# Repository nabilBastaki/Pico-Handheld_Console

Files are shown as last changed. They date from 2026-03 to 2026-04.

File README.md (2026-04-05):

# 🎮 Raspberry Pi Pico 2W Handheld Console (Version 2.0) - No battery - Piezo Buzzer circuit fixed.

Welcome to the Pico 2W Handheld Console project! This repository contains all the hardware files, software firmware, and step-by-step instructions needed to build your own portable gaming device.

---

## 📂 Project Structure

* **/Hardware**: Contains KiCad PCB design files, schematics, and the Bill of Materials (BOM).
* **/Software**: Contains the MicroPython firmware (`main.py`, `diagnostics.py`, `ili9341.py`, `boot.py`).
* **/Guidelines**: **Start here!** These are your step-by-step assembly and user manuals in PDF format.

---

## 🚀 Getting Started (The Build Process)

Please follow the documentation in the **/Guidelines** folder in this specific order:

1.  **01: Soldering & Assembly (PDF)**: Learn the "Golden Rule" of assembly and how to handle the ESOP-8 charger and SOT-23-6 MOSFET.
2.  **02: Initial Power-On Check (PDF)**: Perform critical "Cold Checks" with a multi-meter to ensure your board is safe.
3.  **03: Software Installation (PDF)**: Upload the firmware files to your Pico 2W using Thonny—no coding required!
4.  **04: Console User Manual (PDF)**: Learn how to charge your device, use the "Hold-to-Setup" menu, and handle the LiPo battery safely.
5.  **05: Hardware Troubleshooting (PDF)**: If your screen is white or the buzzer won't stop, use this table to find the fix.
6.  **06: Sign_Off_Sheet (PDF)**: Checklist that includes milestones for each team to keep track of progress and ensure correct procedures.

---

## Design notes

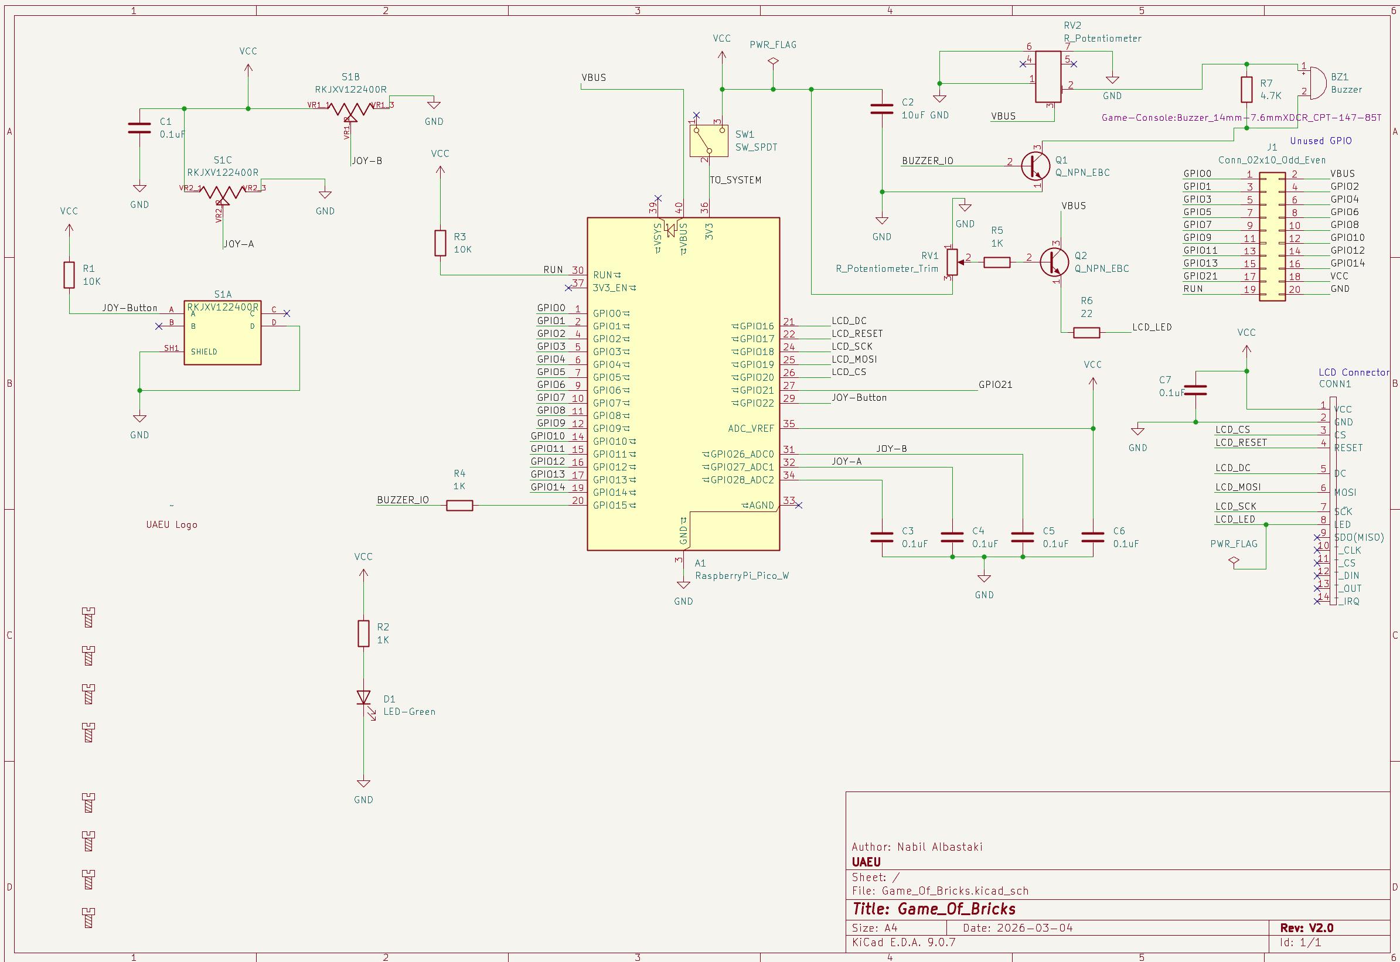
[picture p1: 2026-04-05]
Hardware/Game_Of_Bricks-V2.jpeg

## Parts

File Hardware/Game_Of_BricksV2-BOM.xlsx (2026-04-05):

Reference | Qty | Value | DNP | Exclude from BOM | Exclude from Board | Footprint | Datasheet
A1 | 1 | RaspberryPi_Pico_W |  |  |  | Game-Console:RaspberryPi_Pico_Common_THT | https://datasheets.raspberrypi.com/picow/pico-w-datasheet.pdf
BZ1 | 1 | Buzzer |  |  |  | Game-Console:Buzzer_14mm-7.6mmXDCR_CPT-147-85T | ~
C1*C3*C4*C5*C6*C7 | 6 | 0.1uF |  |  |  | Game-Console:C_1206_3216Metric_Pad1.33x1.80mm_HandSolder | ~
C2 | 1 | 10uF |  |  |  | Game-Console:C_1206_3216Metric_Pad1.33x1.80mm_HandSolder | ~
CONN1 | 1 | ~ |  |  |  | Game-Console:PinSocket_1x14_P2.54mm_Vertical
D1 | 1 | LED-Green |  |  |  | Game-Console:LED_1206_3216Metric_Pad1.42x1.75mm_HandSolder | ~
H1*H2*H3*H4*H5*H6*H7*H8 | 8 | MountingScrew |  | Excluded from BOM |  | Game-Console:MountingHole_3mm | ~
J1 | 1 | Conn_02x10_Odd_Even |  |  |  | Game-Console:PinHeader_2x10_P2.54mm_Horizontal | ~
Q1*Q2 | 2 | Q_NPN_EBC |  |  |  | Game-Console:TO-92L_HandSolder | ~
R1*R3 | 2 | 10K |  |  |  | Game-Console:R_1206_3216Metric_Pad1.30x1.75mm_HandSolder | ~
R2*R4*R5 | 3 | 1K |  |  |  | Game-Console:R_1206_3216Metric_Pad1.30x1.75mm_HandSolder | ~
R6 | 1 | 22 |  |  |  | Game-Console:R_1206_3216Metric_Pad1.30x1.75mm_HandSolder | ~
R7 | 1 | 4.7K |  |  |  | Game-Console:R_1206_3216Metric_Pad1.30x1.75mm_HandSolder | ~
RV1 | 1 | R_Potentiometer_Trim |  |  |  | Game-Console:TRIM_3352T-1-502LF | ~
RV2 | 1 | R_Potentiometer |  |  |  | Game-Console:Potentiometer_RK10J11E_Volume | ~
S1 | 1 | RKJXV122400R |  |  |  | Game-Console:SW_RKJXV122400R
SW1 | 1 | SW_SPDT |  |  |  | Game-Console:SW_Slide_SPDT_Angled_CK_OS102011MA1Q | ~

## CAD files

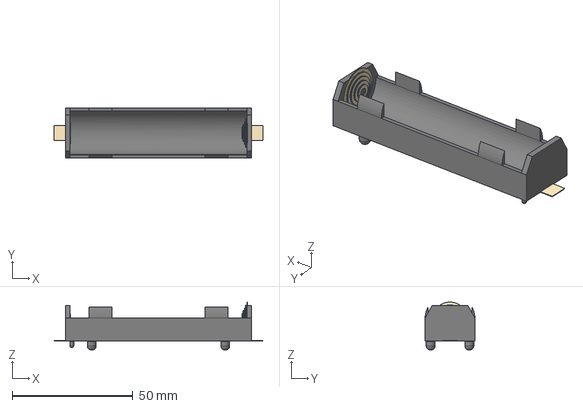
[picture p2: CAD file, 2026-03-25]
Hardware/KiCad_Lib/3dshapes/BatteryHolder_Keystone_1042_1x18650.step
86.4 x 20.6 x 19.8 mm

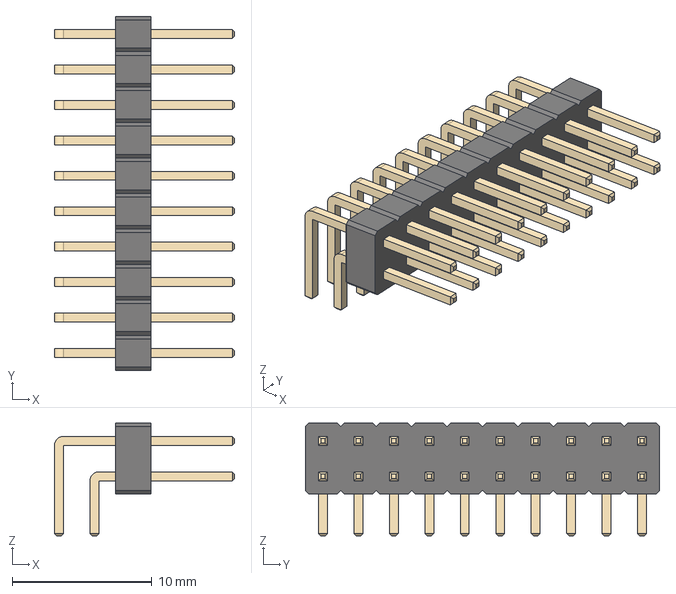
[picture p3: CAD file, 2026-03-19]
Hardware/KiCad_Lib/3dshapes/PinHeader_2x10_P2.54mm_Horizontal.step
12.9 x 25.4 x 8.08 mm

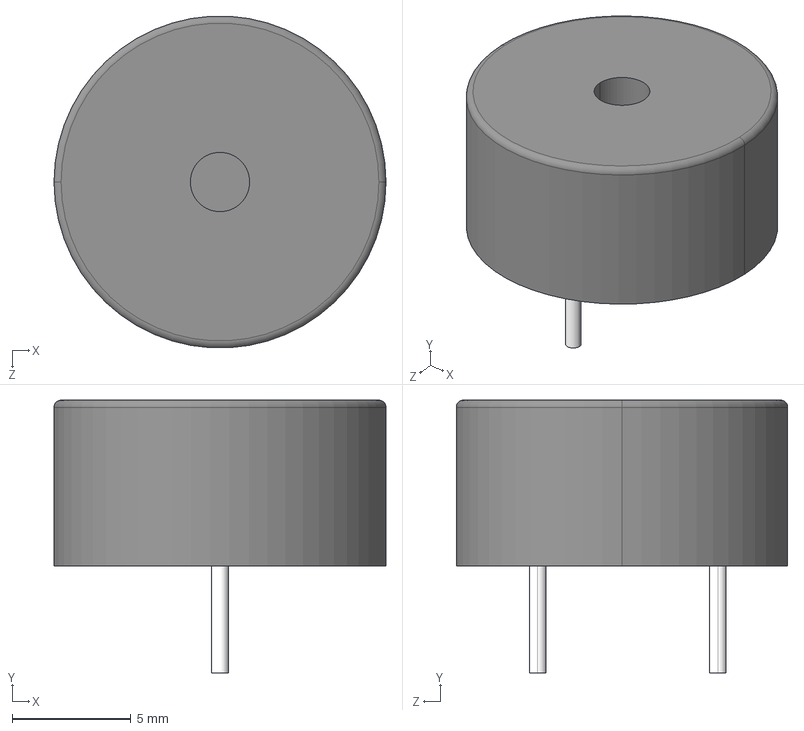
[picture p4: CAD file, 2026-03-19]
Hardware/KiCad_Lib/3dshapes/CPT-147-85T.step
14.0 x 11.5 x 14.0 mm

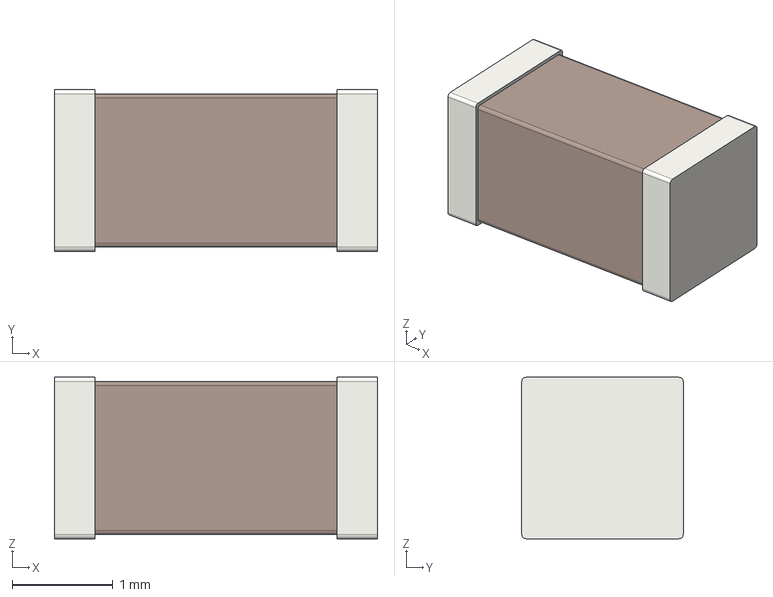
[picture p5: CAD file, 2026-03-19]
Hardware/KiCad_Lib/3dshapes/C_1206_3216Metric.step
3.20 x 1.60 x 1.60 mm

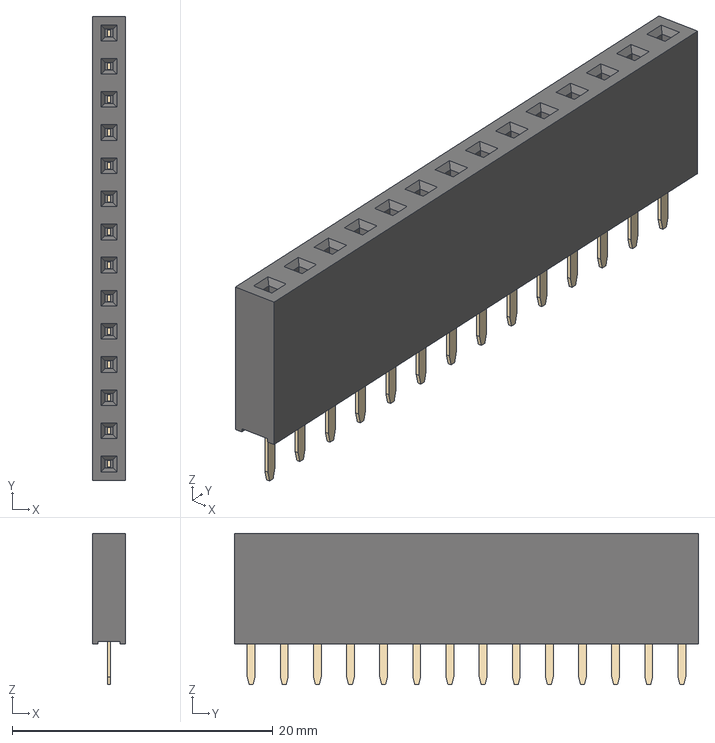
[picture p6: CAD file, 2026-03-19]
Hardware/KiCad_Lib/3dshapes/PinSocket_1x14_P2.54mm_Vertical.step
2.54 x 35.6 x 11.6 mm

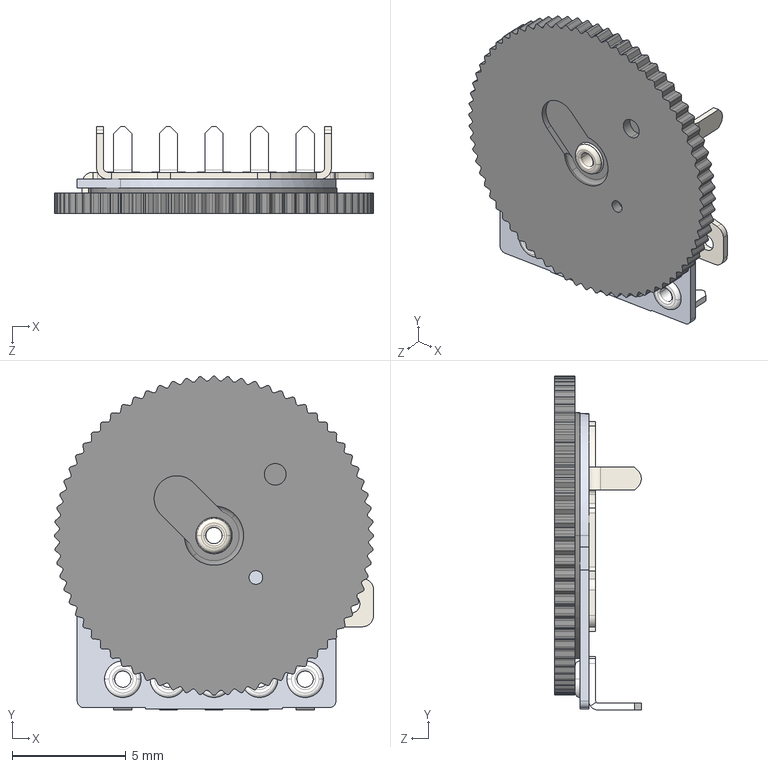
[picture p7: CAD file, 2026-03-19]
Hardware/KiCad_Lib/3dshapes/RK10J11E0034_Volume_VR1.step
14.0 x 14.6 x 3.80 mm

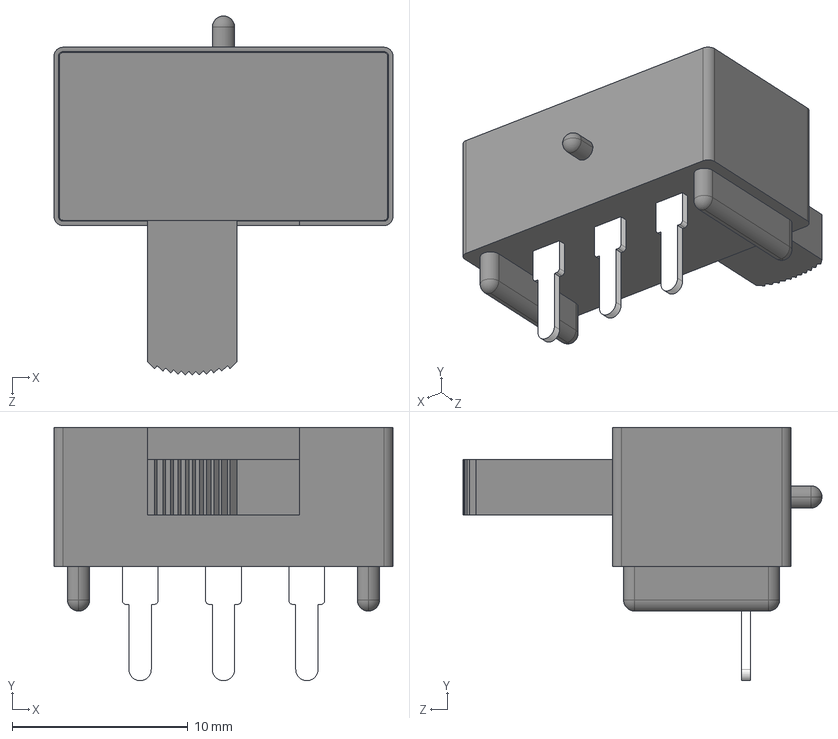
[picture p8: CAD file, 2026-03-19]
Hardware/KiCad_Lib/3dshapes/SPDT_Slide_L102021ML04Q.step
19.3 x 14.4 x 20.4 mm

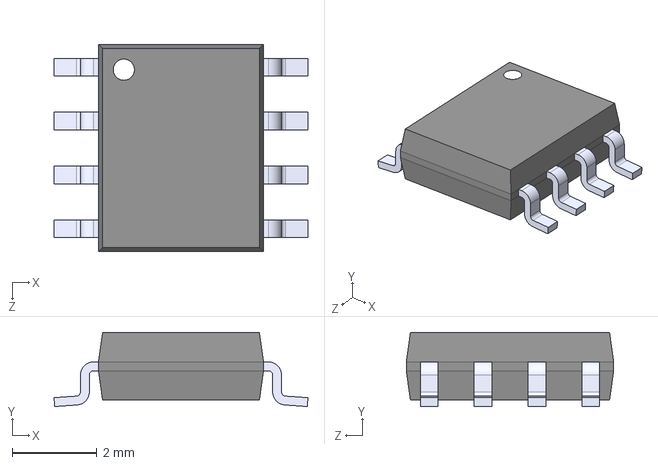
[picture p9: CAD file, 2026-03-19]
Hardware/KiCad_Lib/3dshapes/TP4056.step
6.00 x 1.75 x 4.90 mm

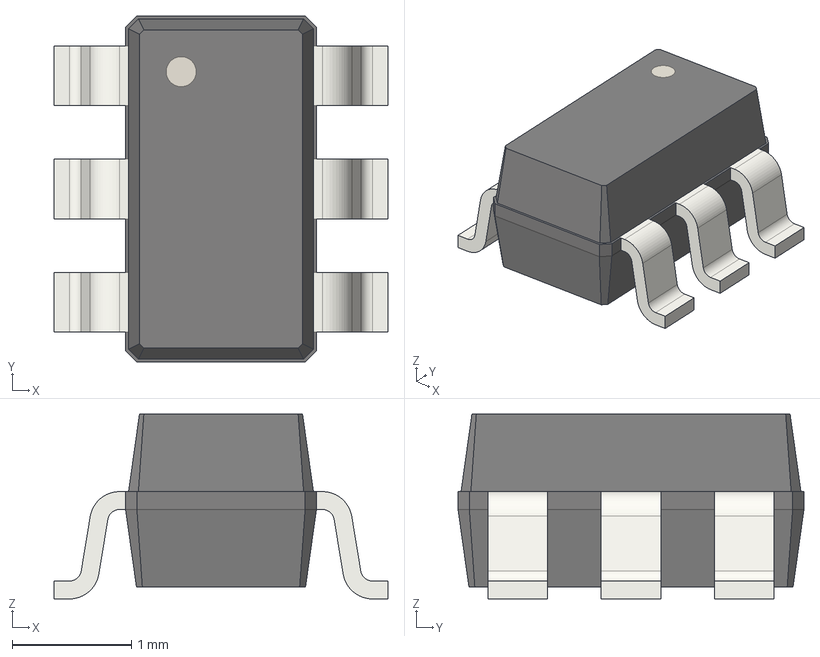
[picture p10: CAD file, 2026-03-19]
Hardware/KiCad_Lib/3dshapes/SOT-23-6.step
2.80 x 2.90 x 1.55 mm

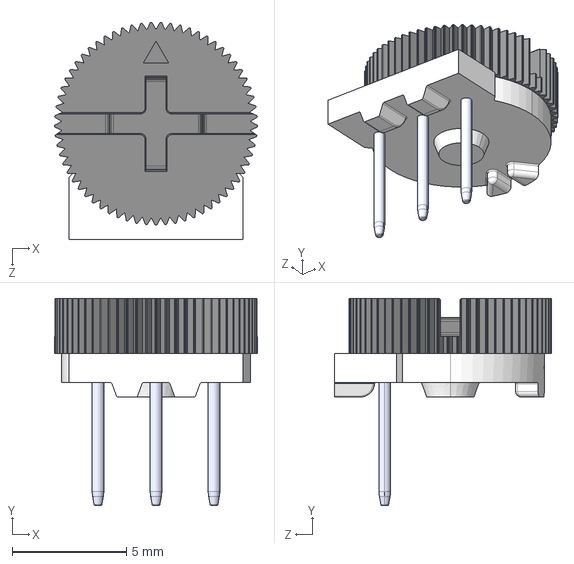
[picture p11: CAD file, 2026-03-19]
Hardware/KiCad_Lib/3dshapes/3352T-1-502LF.step
8.89 x 9.07 x 9.52 mm

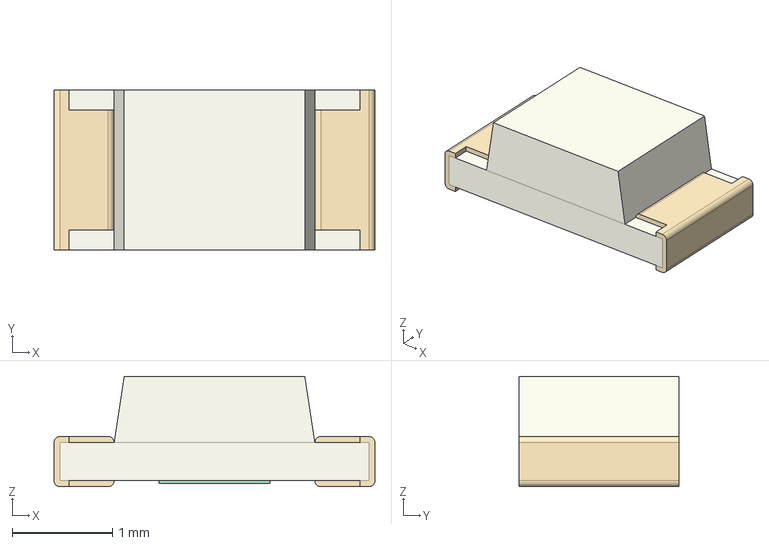
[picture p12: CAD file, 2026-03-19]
Hardware/KiCad_Lib/3dshapes/LED_1206_3216Metric.step
3.20 x 1.60 x 1.10 mm

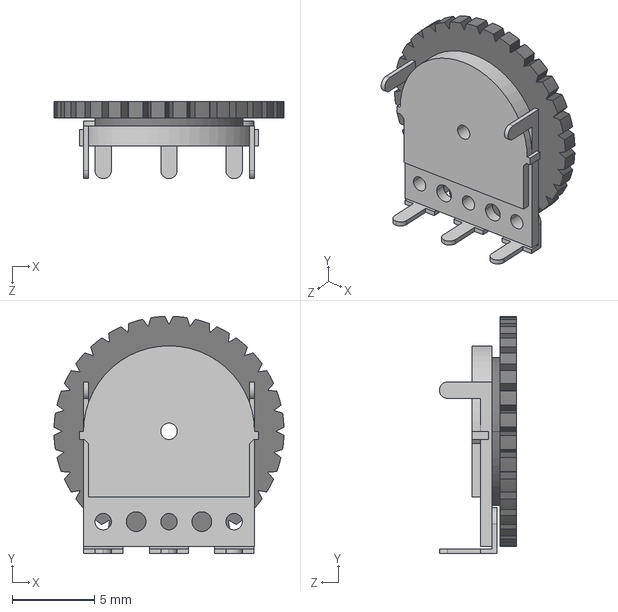
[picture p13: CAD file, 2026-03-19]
Hardware/KiCad_Lib/3dshapes/User Library-RV100F-30-4K1-B15 Potentiometer.STEP
14.0 x 14.4 x 4.70 mm

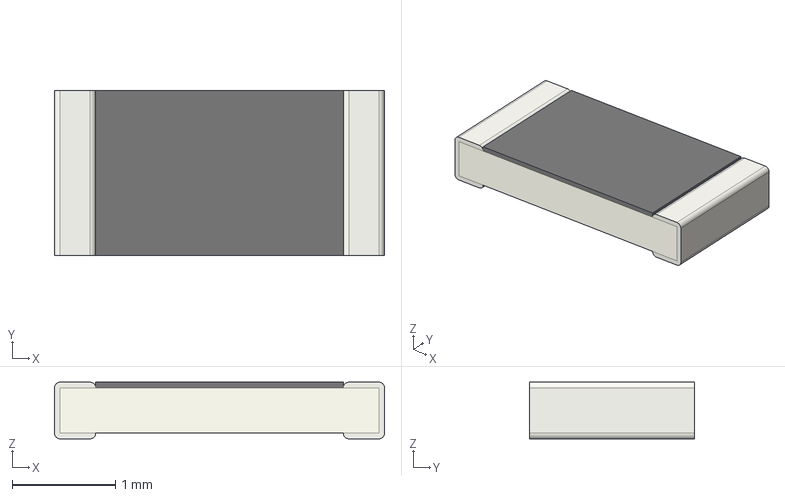
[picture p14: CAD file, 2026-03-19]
Hardware/KiCad_Lib/3dshapes/R_1206_3216Metric.step
3.20 x 1.60 x 0.55 mm

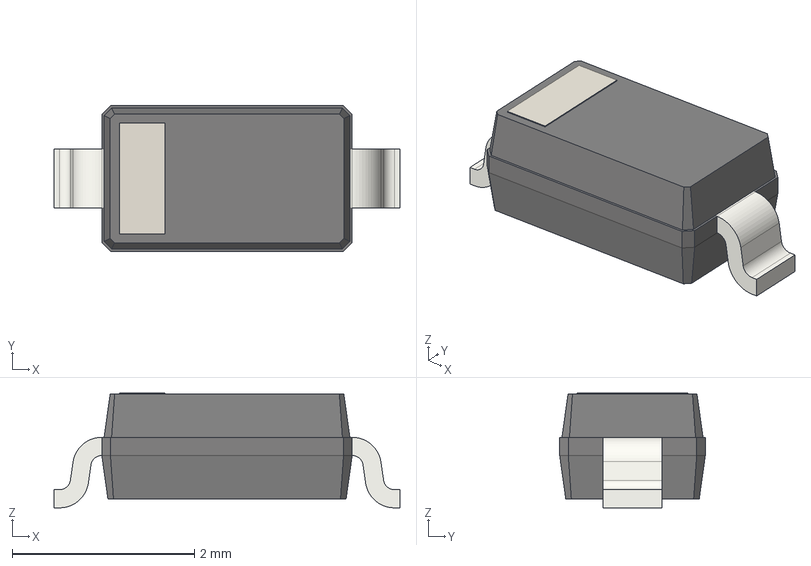
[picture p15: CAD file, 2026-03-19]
Hardware/KiCad_Lib/3dshapes/D_SOD-123.step
3.80 x 1.60 x 1.26 mm

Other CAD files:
Hardware/KiCad_Lib/3dshapes/MountingHoleScrew3mm.step

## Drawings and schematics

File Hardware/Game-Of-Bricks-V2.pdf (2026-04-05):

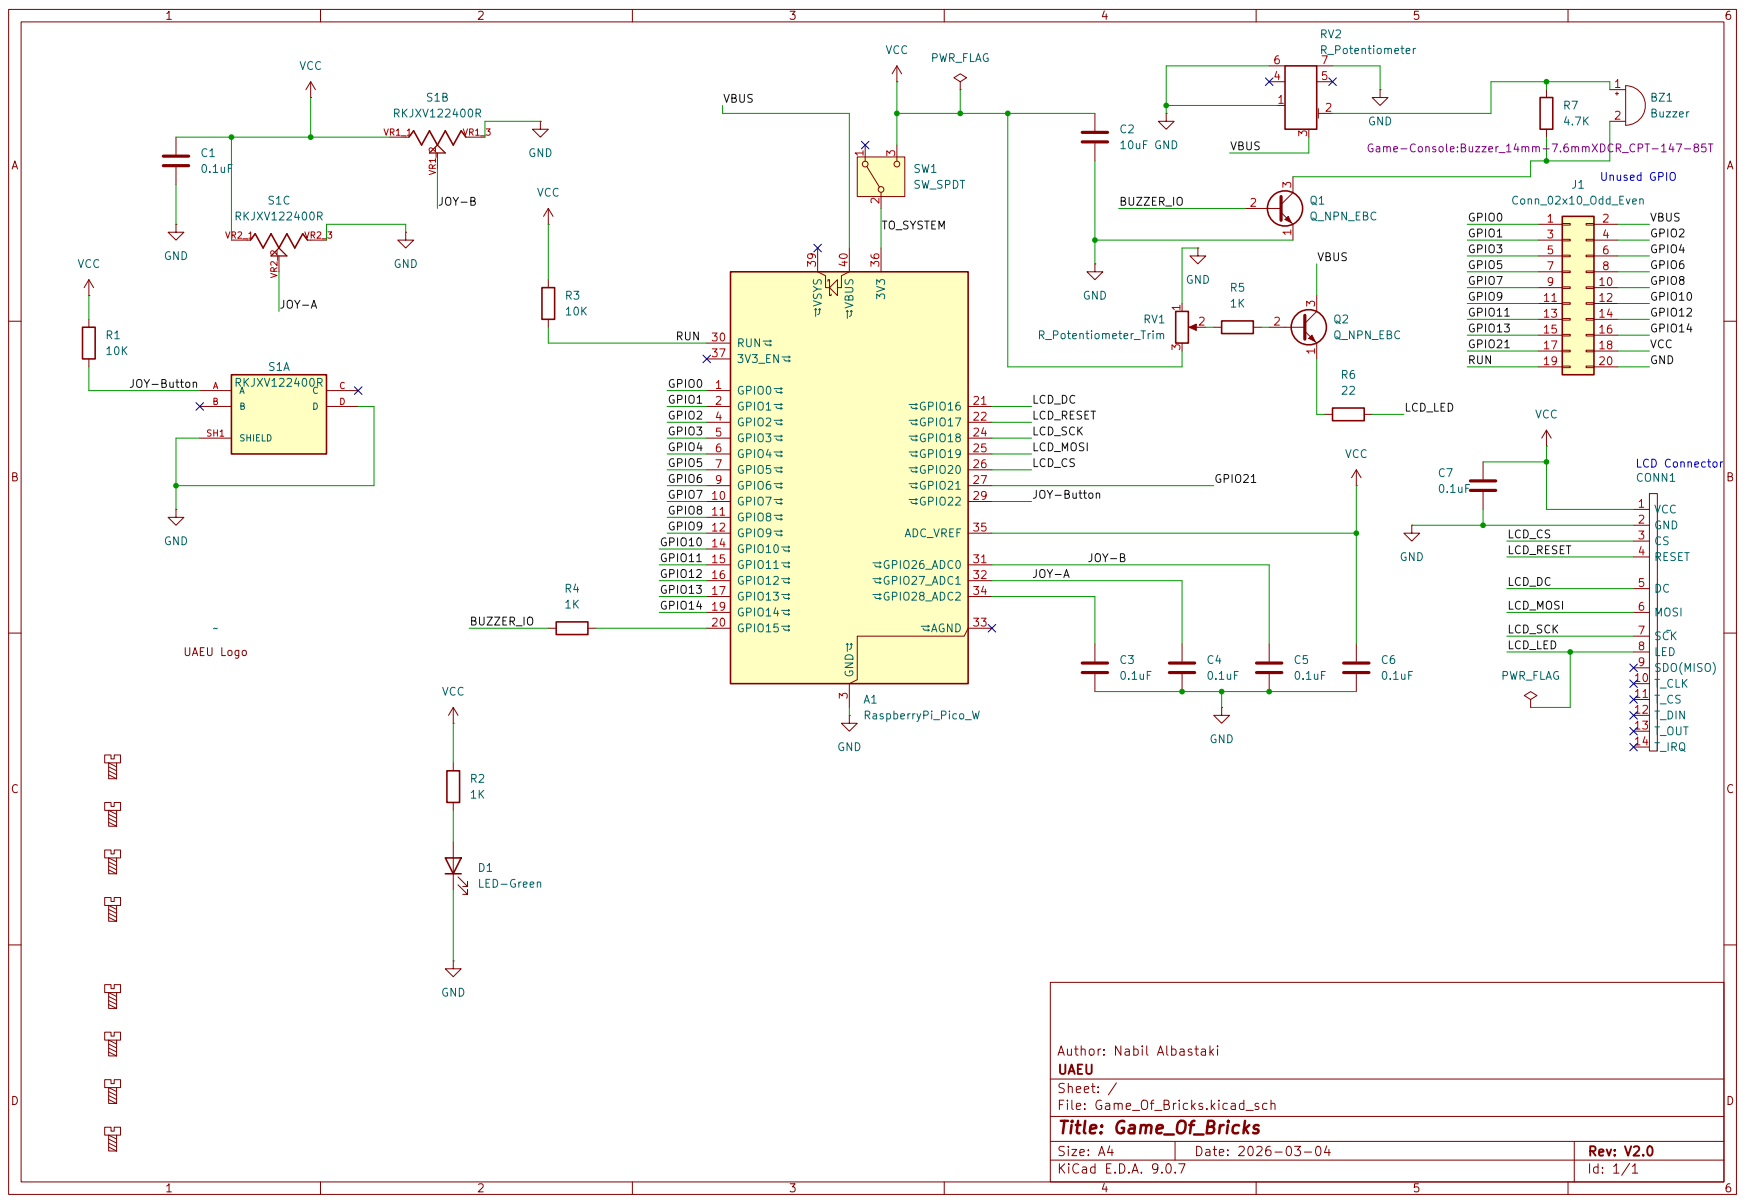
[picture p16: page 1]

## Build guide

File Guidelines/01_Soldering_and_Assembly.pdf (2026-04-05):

Guide 01: Soldering & Assembly
The "Golden Rule" remains to work from the center outward and from shortest to tallest components.
- Step 1: Resistors & Capacitors: Solder the 10kΩ pull-up resistors (R1, R3) and the 0.1µF decoupling capacitors (C1, C3-C7).
- Step 2: Transistors: Solder the NPN transistors (Q1, Q2).
- Step 3: Buzzer & Joystick: Install these taller through-hole parts. Ensure the joystick sits flush against the PCB.
- Step 4: Headers: Solder the two 20-pin female headers for the Raspberry Pi Pico 2W and the 8-pin connector for the LCD.
- Note: Instructions regarding the TP4056 ESOP-8 charger and the FS8205A MOSFET are now obsolete as these components have been removed.

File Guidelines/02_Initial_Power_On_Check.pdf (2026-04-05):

Guide 02: Initial Power-On Check
Since the battery circuit is removed, safety checks focus entirely on the USB 5V (VBUS) rail.
- The Visual Inspection: Check for solder bridges on the female headers and the pins of the NPN transistors (Q1, Q2).
- Multi-Meter "Short Circuit" Test: With the meter in Continuity Mode, place one probe on a GND pin and the other on the VBUS pin. If it stays silent, the power rail is safe.
- Stage 1 Power Up: Plug the Pico 2W into your computer via USB. The tiny green LED on the Pico should blink, indicating the 5V rail is active.
- Note: You no longer need to check battery terminals or the heat of the (removed) charger and MOSFET chips

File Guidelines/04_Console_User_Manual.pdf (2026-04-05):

Guide 04: Console User Manual
The console is now a USB-powered device.
- Power: The device turns on when a Micro-USB cable is connected to the Raspberry Pi Pico.
- Buzzer: The buzzer is now driven by an NPN transistor (Q1) via GPIO15 (BUZZER_IO) for improved sound quality.
- Setup Menu: To enter settings, hold the Joystick Button down while connecting the USB power or flipping the system switch.
- Note: All sections regarding LiPo battery safety, charging LEDs (Red/Green), and low battery warnings are no longer applicable.

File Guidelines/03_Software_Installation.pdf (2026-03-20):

This guide will walk your company through installing the development environment, connecting to the hardware, and transferring the firmware to the Raspberry Pi Pico 2WYou can watch similar steps on YouTube: (https://youtu.be/V5yQ2-BPWLw?si=BpnSXxz7sOUPejI9)

### 1. Download & Install Thonny IDE

Before connecting your hardware, you must install Thonny on your computer.
- For Windows: * Go to thonny.org and download the Windows Installer (64-bit).
- Run the .exe file. If a "Windows protected your PC" message appears, click More info → Run anyway.
- For macOS: * Go to thonny.org and download the .pkg file.
- If blocked by security settings, go to System Settings > Privacy & Security and click Open Anyway.

### 2. Initializing Thonny (First-Time Setup)

Configure Thonny to communicate with the MicroPython language on your console.
1. Connect the Console: Plug your Raspberry Pi Pico 2W into the computer using a micro-USB data cable.
2. Enable the Files Sidebar: In the top menu, go to View Files → .
3. Select the Interpreter: Click the text in the bottom-right corner (likely "Python 3.x") and select MicroPython (Raspberry Pi Pico) from the list.
4. The "Handshake" (Reset): Click the Red Stop Button in the top toolbar.
- The Shell at the bottom should display: MicroPython v1.2x.x... on Raspberry Pi Pico.
- The Files pane will now split into "This computer" (top) and "Raspberry Pi Pico" (bottom).

### 3. Uploading the Firmware

Move the project files from your company's computer to the console's memory.
1. Locate the Files: In the top section (This computer), navigate to your /Software folder.
2. Select the Firmware: Highlight main.py, diagnostics.py, ili9341.py, and boot.py.
3. Transfer: Right-click the highlighted files and select "Upload to /". They will appear in the bottom section (Raspberry Pi Pico).

### 4. Functional Testing & Switching Scripts

The Pico can only run one program at a time. Follow this workflow to test your build.
1. Run Diagnostics: Double-click diagnostics.py in the bottom section and click the Green Play Button.
2. Test Hardware: Verify the screen, joystick, and buzzer are responsive.
3. Switch to Main Game:
- STOP: You must click the Red Stop Button first to end the diagnostic script.
- OPEN: Click the tab for main.py at the top of the editor.
- PLAY: Click the Green Play Button to launch the main console interface.

### 5. Troubleshooting for Companies

- "Device is Busy": A script is currently running. Click the Red Stop Button before trying to upload or run new files.
- Pico Not Found: Ensure you are using a Data Cable. Some cables are "poweronly" and cannot transfer code.
- Missing "Upload to /": Ensure you have right-clicked the files in the top (Computer) section of the pane.

Next Step: Proceed to Guide 04: Console_User_Manual to connect the battery and complete the build!

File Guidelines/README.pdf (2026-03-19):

# 🎮 Raspberry Pi Pico 2W Handheld Console

Welcome to the Pico 2W Handheld Console project! This repository contains all the hardware files, software firmware, and step-by-step instructions needed to build your own portable gaming device.

## 📂 Project Structure

- /Hardware: Contains KiCad PCB design files, schematics, and the Bill of Materials (BOM).
- /Software: Contains the MicroPython firmware (main.py, diagnostics.py, ili9341.py, boot.py).
- /Guidelines: Start here! These are your step-by-step assembly and user manuals in PDF format.

## 🚀 Getting Started (The Build Process)

Please follow the documentation in the /Guidelines folder in this specific order:
1. 01: Soldering & Assembly (PDF): (https://www.google.com/search?q=Guidelines/01_Soldering_and_Assembly.pdf) Learn the "Golden Rule" of assembly and how to handle the ESOP-8 charger and SOT-23-6 MOSFET.
2. 02: Initial Power-On Check (PDF): (https://www.google.com/search?q=Guidelines/02_Initial_Power_On_Check.pdf) Perform critical "Cold Checks" with a multi-meter to ensure your board is safe.
3. 03: Software Installation (PDF): (https://www.google.com/search?q=Guidelines/03_Software_Installation.pdf) Upload the firmware files to your Pico 2W using Thonny—no coding required!
4. 04: Console User Manual (PDF): (https://www.google.com/search?q=Guidelines/04_Console_User_Manual.pdf) Learn how to charge your device, use the "Hold-to-Setup" menu, and handle the LiPo battery safely.
5. 05: Hardware Troubleshooting (PDF): (https://www.google.com/search?q=Guidelines/05_Hardware_Troubleshooting.pdf) If your screen is white or the buzzer won't stop, use this table to find the fix.
6. 06: Sign_Off_Sheet (PDF): Checklist that includes milestones for each team to keep track of progress and ensure correct procedures.

### ⚠️ Important Safety Note

This project uses a Lithium-Polymer (LiPo) battery. You must read Section 2 of the User Manual (https://www.google.com/search?q=Guidelines/04_Console_User_Manual.pdf) before connecting the battery to your PCB to avoid damage or safety hazards.

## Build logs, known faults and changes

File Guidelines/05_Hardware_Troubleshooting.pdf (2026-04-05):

# Guide 05: Hardware Troubleshooting

(V2.0)

99% of issues in this build are related to physical soldering joints. If your console isn't behaving, use this table to find the fix.
Symptom | Probable Cause | The Fix
White Screen | No data connection between Pico and LCD. | Re-solder Pico Pins 21, 22, and 24 (LCD_DC, RESET, and SCK). Check the 8-pin LCD header for cold joints.
Black Screen (No Power) | 5V not reaching the system. | 1. Ensure you are using a USB Data Cable (not a "charge-only" cable). 2. Check soldering on Pico Pin 40 (VBUS) and the SW1 switch.
Buzzer stays ON constantly | Transistor Q1 is shorted or "latched." | Inspect the pins of Q1. Look for a tiny solder bridge between the Collector and Emitter.
Buzzer makes no sound | Logic signal or power not reaching Q1. | 1. Check soldering on Pico Pin 20 (GPIO15). 2. Verify R7 (4.7k) is soldered correctly—this resistor "opens" the transistor gate.
Joystick won't move cursor | Ground or Pin connection broken. | Check soldering on Pico Pins 1, 2, and 26. Ensure the joystick center pins are pushed all the way through the PCB before soldering.
"Device Busy" in Thonny | A script is already running. | Click the Red Stop Button in Thonny to "handshake" with the Pico before trying to upload new code.

### 1. The "Volcano" Rule

Every solder joint should look like a shiny, smooth volcano.

- If a joint looks like a ball/bead, the solder hasn't bonded to the PCB pad (Cold Joint).
- The Fix: Hold your iron tip against the pin and the pad simultaneously for 2 seconds, then add a tiny bit of fresh solder.

### 2. Testing the New Buzzer Circuit

Because we are now using an NPN transistor (Q1) to "switch" the buzzer, you can test it with a multi-meter:
1. Set your meter to DC Voltage.
2. Place the Black probe on GND.
3. Place the Red probe on the center pin (Base) of Q1 while running the diagnostics.py script.
4. You should see the voltage jump between 0V and ~3.3V. If you see 3.3V at the base but no sound, the transistor or the buzzer itself is likely soldered incorrectly.

### 3. Screen Contrast/Flicker

If the screen flickers when the buzzer sounds:
- Check the soldering on your decoupling capacitors (C1, C3-C7). These are responsible for "smoothing out" the power when the buzzer draws a sudden burst of current.

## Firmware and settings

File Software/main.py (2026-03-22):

import machine
import time
import random
import os
from ili9341 import Display
from machine import ADC, Pin, PWM

# --- 0. CONSTANTS & CONFIGURATION ---
SCREEN_W = 320
SCREEN_H = 240
BAR_H = 25
BAR_COL = 0x001F

PADDLE_Y = 215
PADDLE_H = 8
P_COL = 0x07FF

BALL_SIZE = 8
BALL_COL = 0xFFFF

BRICK_W = 38
BRICK_H = 10
FILE_HS = 'highscore.txt'

# --- 1. INITIALIZATION & HARDWARE ---
try:
    with open(FILE_HS, 'r') as f:
        pass 
except OSError:
    with open(FILE_HS, 'w') as f:
        f.write('0')

led = Pin("LED", Pin.OUT)
spi = machine.SPI(0, baudrate=24000000, mosi=Pin(19), sck=Pin(18))

rst_pin = Pin(17, Pin.OUT)
rst_pin.value(0)
time.sleep(0.1)
rst_pin.value(1)
time.sleep(0.1)

scr = Display(spi, cs=Pin(20), dc=Pin(16), rst=Pin(17))

joy_x = ADC(Pin(26))
joy_y = ADC(Pin(27))
btn_joy = Pin(22, Pin.IN, Pin.PULL_UP)

buzzer = PWM(Pin(15))
buzzer.duty_u16(0)

# --- 2. FONT DATA ---
FONT = {
    '0':[0x3E,0x41,0x41,0x41,0x3E],'1':[0x00,0x42,0x7F,0x40,0x00],
    '2':[0x42,0x61,0x51,0x49,0x46],'3':[0x21,0x41,0x45,0x4B,0x31],
    '4':[0x18,0x14,0x12,0x7F,0x10],'5':[0x27,0x45,0x45,0x45,0x39],
    '6':[0x3C,0x4A,0x49,0x49,0x30],'7':[0x01,0x71,0x09,0x05,0x03],
    '8':[0x36,0x49,0x49,0x49,0x36],'9':[0x06,0x49,0x49,0x29,0x1E],
    'A':[0x7E,0x11,0x11,0x11,0x7E],'B':[0x7F,0x49,0x49,0x49,0x36],
    'C':[0x3E,0x41,0x41,0x41,0x22],'D':[0x7F,0x41,0x41,0x22,0x1C],
    'E':[0x7F,0x49,0x49,0x49,0x41],'F':[0x7F,0x09,0x09,0x09,0x01],
    'G':[0x3E,0x41,0x49,0x49,0x7A],'H':[0x7F,0x08,0x08,0x08,0x7F],
    'I':[0x00,0x41,0x7F,0x41,0x00],'J':[0x40,0x40,0x41,0x3F,0x01],
    'K':[0x7F,0x08,0x14,0x22,0x41],'L':[0x7F,0x40,0x40,0x40,0x40],
    'M':[0x7F,0x02,0x0C,0x02,0x7F],'N':[0x7F,0x04,0x08,0x10,0x7F],
    'O':[0x3E,0x41,0x41,0x41,0x3E],'P':[0x7F,0x09,0x09,0x09,0x06],
    'Q':[0x3E,0x41,0x51,0x21,0x5E],'R':[0x7F,0x09,0x19,0x29,0x46],
    'S':[0x26,0x49,0x49,0x49,0x32],'T':[0x01,0x01,0x7F,0x01,0x01],
    'U':[0x3F,0x40,0x40,0x40,0x3F],'V':[0x1F,0x20,0x40,0x20,0x1F],
    'W':[0x7F,0x20,0x18,0x20,0x7F],'X':[0x63,0x14,0x08,0x14,0x63],
    'Y':[0x07,0x08,0x70,0x08,0x07],'Z':[0x61,0x51,0x49,0x45,0x43],
    ' ':[0,0,0,0,0], ':':[0x00,0x36,0x36,0x00,0x00], '!':[0x00,0x00,0x5F,0x00,0x00]
}

# --- 3. CLASSES ---
class Ball:
    def __init__(self, size):
        self.size = size
        self.x = 160.0
        self.y = 150.0
        self.old_x = self.x
        self.old_y = self.y
        self.dx = 3.0
        self.dy = -3.0

    def move(self):
        self.old_x = self.x
        self.old_y = self.y
        self.x += self.dx
        self.y += self.dy

    def erase(self):
        scr.fill_rect(int(self.old_x), int(self.old_y), self.size, self.size, 0)

    def draw(self):
        if int(self.x) != int(self.old_x) or int(self.y) != int(self.old_y):
            scr.fill_rect(int(self.old_x), int(self.old_y), self.size, self.size, 0)
            scr.fill_rect(int(self.x), int(self.y), self.size, self.size, BALL_COL)

class Paddle:
    def __init__(self, y, height, color):
        self.y = y
        self.height = height
        self.width = int(settings["PADDLE"])
        self.color = color
        self.x = 160.0 - (self.width / 2)
        self.old_x = self.x

    def move(self, target_x):
        self.old_x = self.x
        self.width = int(settings["PADDLE"])
        self.x = max(2, min(SCREEN_W - 2 - self.width, target_x))

    def draw(self, force=False):
        x_int, old_x_int = int(self.x), int(self.old_x)
        if force:
            scr.fill_rect(x_int, self.y, self.width, self.height, self.color)
            return
        if x_int != old_x_int:
            diff = x_int - old_x_int
            if abs(diff) >= self.width:
                scr.fill_rect(old_x_int, self.y, self.width, self.height, 0)
                scr.fill_rect(x_int, self.y, self.width, self.height, self.color)
            elif diff > 0:
                scr.fill_rect(old_x_int, self.y, diff, self.height, 0)
                scr.fill_rect(old_x_int + self.width, self.y, diff, self.height, self.color)
            else:
                abs_diff = abs(diff)
                scr.fill_rect(x_int + self.width, self.y, abs_diff, self.height, 0)
                scr.fill_rect(x_int, self.y, abs_diff, self.height, self.color)
            self.old_x = self.x

# --- 4. STATE & UTILS ---
def load_highscore():
    try:
        with open(FILE_HS, "r") as f: return int(f.read())
    except: return 0

def save_highscore(val):
    try:
        with open(FILE_HS, "w") as f:
            f.write(str(val)); f.flush(); os.sync()
    except: pass

DIFF_NAMES = ["EASY", "NORMAL", "HARD"]
settings = {"SPEED": 4.0, "LIVES": 3, "PADDLE": 60, "VOLUME": 2, "DIFF": 1}

score, high_score = 0, load_highscore()
lives, is_demo = 3, True
sound_timer, bricks = 0, []
l_score, l_high, l_lives, l_time = -1, -1, -1, -1

ball = Ball(BALL_SIZE)
paddle = Paddle(PADDLE_Y, PADDLE_H, P_COL)

def play_sound(freq, duration_ms):
    global sound_timer
    if settings["VOLUME"] == 0: return
    try:
        buzzer.freq(int(freq))
        buzzer.duty_u16(settings["VOLUME"] * 1500)
        sound_timer = time.ticks_ms() + duration_ms
    except: pass

def draw_text(x, y, txt, col, bg=0):
    for char in str(txt).upper():
        bm = FONT.get(char, [0x7F, 0x41, 0x41, 0x41, 0x7F])
        scr.fill_rect(int(x), int(y), 10, 14, bg)
        for i in range(5):
            for j in range(7):
                if (bm[i] >> j) & 1: scr.fill_rect(int(x+i*2), int(y+j*2), 2, 2, col)
        x += 12

def update_hud(force=False):
    global l_score, l_high, l_lives, l_time
    bg = BAR_COL
    if force:
        scr.fill_rect(0, 0, SCREEN_W, BAR_H, bg)
        draw_text(70, 5, "H", 0x07E0, bg)
        draw_text(150, 5, "S", 0x07FF, bg)
        draw_text(240, 5, "T", 0xFFE0, bg)
    
    if high_score != l_high or force:
        draw_text(90, 5, "{:03d}".format(high_score), 0xFFFF, bg)
        l_high = high_score
        
    if score != l_score or force:
        draw_text(170, 5, "{:03d}".format(score), 0xFFFF, bg)
        l_score = score
        
    if lives != l_lives or force:
        scr.fill_rect(5, 5, 65, 18, bg) # Clear heart area
        c = 0xF800 # Red
        
        if lives <= 4:
            # Show individual hearts
            for i in range(max(0, lives)):
                hx = 5 + (i * 13)
                hy = 8
                scr.fill_rect(hx+1, hy, 2, 1, c)
                scr.fill_rect(hx+4, hy, 2, 1, c)
                scr.fill_rect(hx, hy+1, 7, 2, c)
                scr.fill_rect(hx+1, hy+3, 5, 1, c)
                scr.fill_rect(hx+2, hy+4, 3, 1, c)
                scr.fill_rect(hx+3, hy+5, 1, 1, c)
        else:
            # Show one heart + "X" and number
            hx, hy = 5, 8
            scr.fill_rect(hx+1, hy, 2, 1, c)
            scr.fill_rect(hx+4, hy, 2, 1, c)
            scr.fill_rect(hx, hy+1, 7, 2, c)
            scr.fill_rect(hx+1, hy+3, 5, 1, c)
            scr.fill_rect(hx+2, hy+4, 3, 1, c)
            scr.fill_rect(hx+3, hy+5, 1, 1, c)
            draw_text(18, 5, "X" + str(lives), 0xFFFF, bg)
            
        l_lives = lives
        
    cur_t = (time.ticks_ms() // 1000) % 1000
    if cur_t != l_time or force:
        draw_text(260, 5, "{:03d}".format(cur_t), 0xFFFF, bg)
        l_time = cur_t

# --- 5. LOGIC ---
def gen_bricks():
    global bricks
    bricks = []
    colors = [0xF800, 0xFFE0, 0x07E0]
    for r in range(3):
        for c in range(7):
            is_ex = random.random() < 0.15
            bricks.append([10 + c * 44, 45 + (r * 15), 0xF81F if is_ex else colors[r], True, is_ex])

def reset_ball_pos():
    ball.x = float(paddle.x + (paddle.width // 2) - 4)
    ball.y = float(PADDLE_Y - 12)
    ball.old_x, ball.old_y = ball.x, ball.y
    ball.dx = float(settings["SPEED"])
    ball.dy = -abs(float(settings["SPEED"]))

def reset_logic():
    global score, lives
    score, lives = 0, settings["LIVES"]
    paddle.width = int(settings["PADDLE"])
    paddle.x = 160.0 - (paddle.width // 2)
    paddle.old_x = paddle.x
    scr.fill(0)
    gen_bricks()
    for b in bricks: scr.fill_rect(int(b[0]), int(b[1]), BRICK_W, BRICK_H, b[2])
    update_hud(True)
    paddle.draw(force=True)
    reset_ball_pos()

def check_collisions():
    global score, high_score, lives, is_demo
    if ball.x <= 2 or ball.x >= (SCREEN_W - ball.size): ball.dx *= -1; play_sound(600, 20)
    if ball.y <= BAR_H: ball.dy = abs(ball.dy); ball.y = BAR_H + 1; play_sound(600, 20)
    if (PADDLE_Y - 8 <= ball.y <= PADDLE_Y) and (paddle.x - 5 <= ball.x <= paddle.x + paddle.width + 5):
        ball.dy = -abs(ball.dy); ball.y = PADDLE_Y - 9; play_sound(800, 30)
    for b in bricks:
        if b[3] and b[0] < ball.x < b[0] + BRICK_W and b[1] < ball.y < b[1] + BRICK_H:
            ball.dy *= -1; b[3] = False
            scr.fill_rect(int(b[0]), int(b[1]), BRICK_W, BRICK_H, 0)
            if not is_demo:
                score += 10
                if score > high_score: high_score = score; save_highscore(high_score)
            if b[4]: lives += 1; play_sound(2000, 20)
            else: play_sound(1000, 15)
            if not any(bk[3] for bk in bricks):
                if not is_demo: score += 100
                if settings["DIFF"] == 1: settings["SPEED"] += 0.3
                elif settings["DIFF"] == 2:
                    settings["SPEED"] += 0.6; settings["PADDLE"] = max(20, settings["PADDLE"] - 5)
                # SYNC BEFORE DRAW
                ball.x = float(paddle.x + (paddle.width // 2) - 4)
                ball.y = float(PADDLE_Y - 12)
                ball.old_x, ball.old_y = ball.x, ball.y
                scr.fill(0); gen_bricks()
                for bk in bricks: scr.fill_rect(int(bk[0]), int(bk[1]), BRICK_W, BRICK_H, bk[2])
                paddle.draw(force=True); update_hud(True); ball.draw()
            break
    if ball.y > SCREEN_H:
        if not is_demo:
            lives -= 1
            if lives <= 0:
                play_sound(150, 600); scr.fill_rect(60, 100, 200, 50, 0)
                draw_text(110, 110, "GAME OVER", 0xF800); draw_text(85, 130, "CLICK JOYSTICK", 0xFFFF)
                time.sleep(0.6); buzzer.duty_u16(0)
                while btn_joy.value() == 1: time.sleep(0.01)
                is_demo = True; reset_logic()
            else: reset_ball_pos(); play_sound(200, 100)
        else: ball.dy = -abs(ball.dy); ball.y = SCREEN_H - 10

# --- 6. MENUS ---
def run_setup_menu():
    scr.fill(0); draw_text(110, 20, "SETUP", 0x07FF); draw_text(50, 215, "CLICK TO START", 0x07E0)
    sel, keys = 0, ["SPEED", "LIVES", "PADDLE", "VOLUME", "DIFF"]
    while True:
        for i, k in enumerate(keys):
            col = 0xFFFF if i == sel else 0x4444
            draw_text(50, 50 + (i*30), k, col); scr.fill_rect(170, 50 + (i*30), 100, 15, 0)
            val = DIFF_NAMES[settings[k]] if k == "DIFF" else str(int(settings[k]))
            draw_text(170, 50 + (i*30), val, col)
        while True:
            jy, jx = joy_y.read_u16(), joy_x.read_u16()
            if jy < 15000 or jy > 50000 or jx < 15000 or jx > 50000 or btn_joy.value() == 0: break
            time.sleep(0.01)
        if jy < 15000: sel = (sel - 1) % len(keys)
        elif jy > 50000: sel = (sel + 1) % len(keys)
        elif jx < 15000:
            if keys[sel] == "PADDLE": settings[keys[sel]] = min(120, settings[keys[sel]] + 10)
            elif keys[sel] == "VOLUME": settings[keys[sel]] = min(4, settings[keys[sel]] + 1)
            elif keys[sel] == "DIFF": settings[keys[sel]] = (settings[keys[sel]] + 1) % 3
            else: settings[keys[sel]] = min(15, settings[keys[sel]] + 1)
        elif jx > 50000:
            if keys[sel] == "PADDLE": settings[keys[sel]] = max(20, settings[keys[sel]] - 10)
            elif keys[sel] == "VOLUME": settings[keys[sel]] = max(0, settings[keys[sel]] - 1)
            elif keys[sel] == "DIFF": settings[keys[sel]] = (settings[keys[sel]] - 1) % 3
            else: settings[keys[sel]] = max(1, settings[keys[sel]] - 1)
        if btn_joy.value() == 0: time.sleep(0.3); break
        time.sleep(0.15)

# --- 7. BOOT & MAIN ---
if btn_joy.value() == 0: run_setup_menu()
reset_logic()

while True:
    t_start = time.ticks_ms()
    if sound_timer != 0 and time.ticks_ms() > sound_timer: buzzer.duty_u16(0); sound_timer = 0
    if btn_joy.value() == 0 and is_demo: is_demo = False; reset_logic(); time.sleep(0.2)
    if is_demo: paddle.move(ball.x - (paddle.width // 2))
    else:
        jx = joy_x.read_u16()
        if jx < 20000: paddle.move(paddle.x + settings["SPEED"] + 4)
        elif jx > 45000: paddle.move(paddle.x - settings["SPEED"] - 4)
    ball.move(); check_collisions()
    ball.draw(); paddle.draw(); update_hud()
    while time.ticks_diff(time.ticks_ms(), t_start) < 16: pass

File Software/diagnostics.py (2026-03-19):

import machine, time
from machine import Pin, ADC, PWM
from ili9341 import Display

# --- 1. HARDWARE ---
spi = machine.SPI(0, baudrate=24000000, mosi=Pin(19), sck=Pin(18))

# PCB MOSFET GATE (Uncomment when moving to final PCB)
# gate = Pin(14, Pin.OUT); gate.value(1)

# LCD RESET (Fixes fading)
rst = Pin(17, Pin.OUT)
rst.value(0); time.sleep(0.1); rst.value(1); time.sleep(0.1)

scr = Display(spi, cs=Pin(20), dc=Pin(16), rst=Pin(17))
joy_x, joy_y = ADC(Pin(26)), ADC(Pin(27))
btn_joy = Pin(22, Pin.IN, Pin.PULL_UP)
buzzer = PWM(Pin(15))
buzzer.duty_u16(0)

print("--- UNIVERSAL DIAGNOSTIC READY ---")

while True:
    x_raw, y_raw = joy_x.read_u16(), joy_y.read_u16()
    
    # --- CLAMPED COORDINATES ---
    # (Value / Max) * (ScreenSize - ObjectSize)
    # This keeps the 12x12 square fully visible at the 320/240 edges
    # if joystick to left moves paddle to right, use: cur_x = (320 - 12) - int((x_raw / 65535) * (320 - 12)) instead.
    cur_x = int((x_raw / 65535) * (320 - 12)) 
    cur_y = int((y_raw / 65535) * (240 - 12))
    
    scr.fill(0)
    
    if btn_joy.value() == 0:
        color = 0xF800 # Red
        buzzer.freq(1000)
        buzzer.duty_u16(2000)
    else:
        color = 0xFFFF # White
        buzzer.duty_u16(0)
        
    scr.fill_rect(cur_x, cur_y, 12, 12, color)
    time.sleep(0.04) # Slightly faster refresh

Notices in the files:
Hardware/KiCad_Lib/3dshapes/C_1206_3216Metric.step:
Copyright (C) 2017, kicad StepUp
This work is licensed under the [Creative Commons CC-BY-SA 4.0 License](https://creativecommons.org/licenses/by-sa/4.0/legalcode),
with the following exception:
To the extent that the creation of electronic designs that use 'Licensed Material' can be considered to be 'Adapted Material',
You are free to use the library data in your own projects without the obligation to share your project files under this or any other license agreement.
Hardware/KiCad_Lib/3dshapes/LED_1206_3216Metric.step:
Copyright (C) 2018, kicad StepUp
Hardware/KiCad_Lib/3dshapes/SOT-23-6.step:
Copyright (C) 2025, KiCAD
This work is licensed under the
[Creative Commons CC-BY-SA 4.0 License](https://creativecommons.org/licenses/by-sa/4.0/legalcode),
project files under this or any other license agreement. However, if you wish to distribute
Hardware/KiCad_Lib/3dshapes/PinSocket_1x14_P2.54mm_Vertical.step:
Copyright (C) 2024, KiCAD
